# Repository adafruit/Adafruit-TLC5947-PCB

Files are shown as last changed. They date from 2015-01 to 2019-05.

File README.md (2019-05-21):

## Adafruit 24-Channel 12-bit PWM LED Driver - SPI Interface TLC5947 PCB
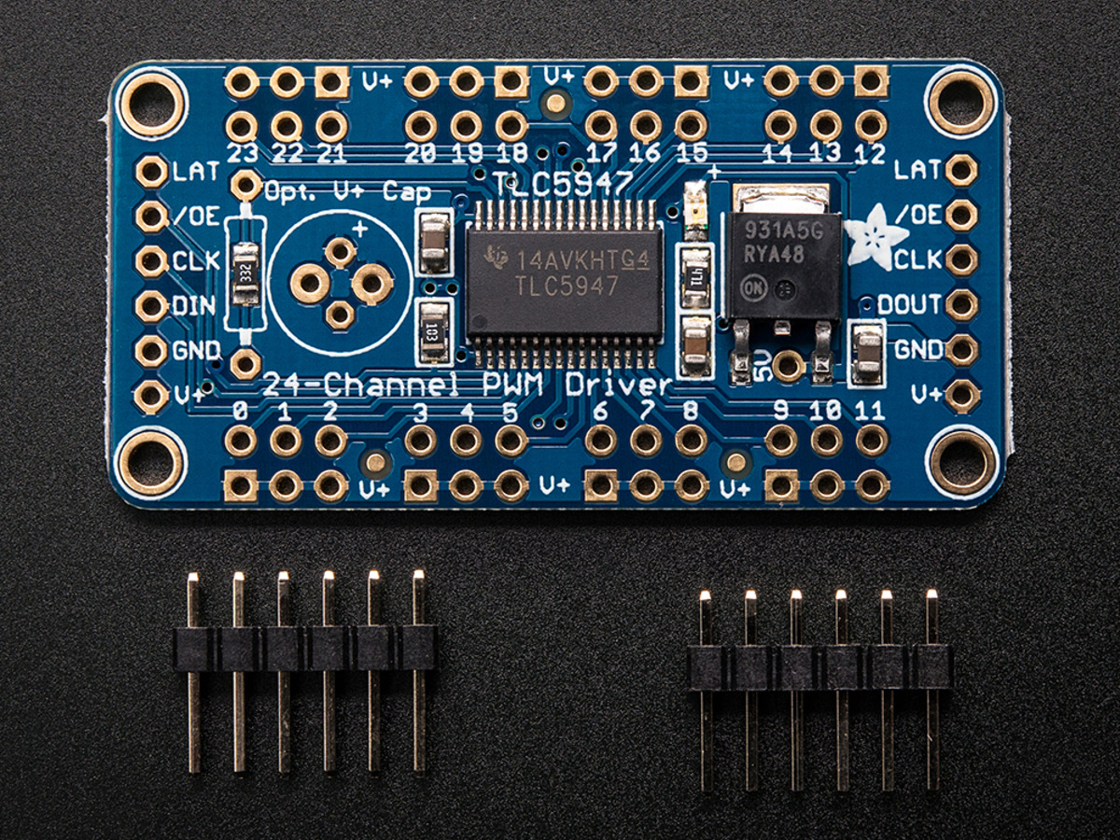
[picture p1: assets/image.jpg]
<a href="http://www.adafruit.com/products/1429"><br/>
Click here to purchase one from the Adafruit shop</a>

For all of you out there who want to control 24 channels of PWM, we salute you! We also would like you to check out this breakout board for the TLC5947 PWM driver chip. This chip can control 24 separate channels of 12-bit PWM output. Designed (and ideal) for LED control, this board is not good for driving servos. If you need to drive servos, we have a controller for that over here.

Only three "SPI" pins are required to send data (our Arduino library shows how to to use any digital microcontroller pins). Best of all, the design is completely chainable. As long as there's enough power for all the boards you can chain as many as you'd like, like a little trail of blue PCBs stretching out into the sunset. Each of the 24 output's is constant-current and open drain. You can drive multiple LEDs in series, with a V+ anode supply of up to 30V. If you want to drive something that requires a digital input, you must use a pullup resistor from the drive pin to your logic level to create the full waveform.

PCB files for Adafruit TLC5947 24-channel PWM Driver PCB. The format is EagleCAD schematic and board layout
- http://www.adafruit.com/products/1429

### License

Adafruit invests time and resources providing this open source design, please support Adafruit and open-source hardware by purchasing products from [Adafruit](https://www.adafruit.com)!

All text above must be included in any redistribution

Designed by Limor Fried/Ladyada for Adafruit Industries.
Creative Commons Attribution/Share-Alike, all text above must be included in any redistribution. 
See license.txt for additional information.

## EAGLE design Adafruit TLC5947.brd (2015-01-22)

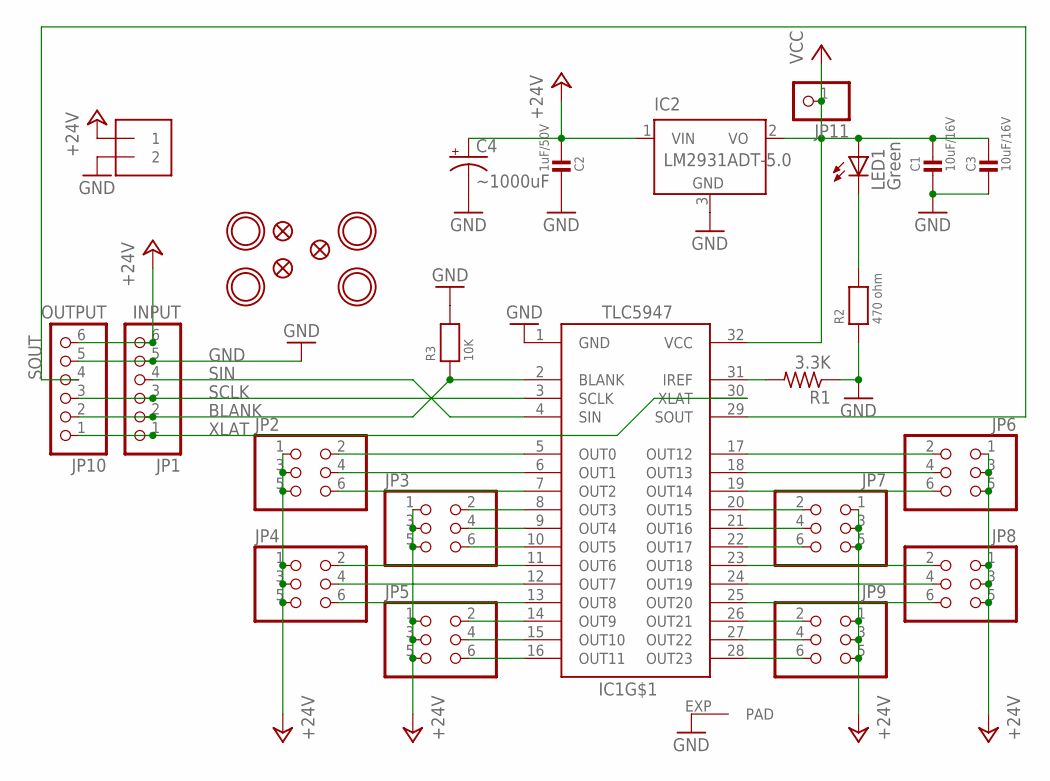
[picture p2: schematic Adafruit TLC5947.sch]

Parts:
C1, C3: 10uF/16V; 0805
C2: 1uF/50V; 0805
C4: ~1000uF; E3,5-8
FID1, FID2, FID3: FIDUCIAL""; FIDUCIAL_1MM
IC1: TLC5947-DAP; HTSSOP32DAP
IC2: LM2931ADT-5.0; TO252
J1: 1X2-3.5MM
JP1: INPUT; 1X06-CLEANBIG
JP2, JP3, JP4, JP5, JP6, JP7, JP8, JP9: HEADER-2X3; 2X03_ROUND_70MIL
JP10: OUTPUT; 1X06-CLEANBIG
JP11: PINHD-1X1CB; 1X01-CLEANBIG
LED1: Green; CHIP-LED0805
R1: 3.3K; 0805-THM
R2: 470 ohm; 0805
R3: 10K; 0805
U$1, U$2, U$3, U$4: MOUNTINGHOLE2.5; MOUNTINGHOLE_2.5_PLATED

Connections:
+24V: C2.1, C4.+, IC2.1 (VIN), J1.1, JP1.6, JP2.1, JP2.3, JP2.5, JP3.1, JP3.3, JP3.5, JP4.1, JP4.3, JP4.5, JP5.1, JP5.3, JP5.5, JP6.1, JP6.3, JP6.5, JP7.1, JP7.3, JP7.5, JP8.1, JP8.3, JP8.5, JP9.1, JP9.3, JP9.5, JP10.6
BLANK: IC1.2 (BLANK), JP1.2, JP10.2, R3.1
GND: C1.2, C2.2, C3.2, C4.-, IC1.1 (GND), IC1.EXP (PAD), IC2.3 (GND), J1.2, JP1.5, JP10.5, R1.1, R2.1, R3.2
unnamed: LED1.C, R2.2
unnamed: IC1.31 (IREF), R1.2
unnamed: IC1.5 (OUT0), JP2.2
unnamed: IC1.6 (OUT1), JP2.4
unnamed: IC1.7 (OUT2), JP2.6
unnamed: IC1.8 (OUT3), JP3.2
unnamed: IC1.9 (OUT4), JP3.4
unnamed: IC1.10 (OUT5), JP3.6
unnamed: IC1.11 (OUT6), JP4.2
unnamed: IC1.12 (OUT7), JP4.4
unnamed: IC1.13 (OUT8), JP4.6
unnamed: IC1.14 (OUT9), JP5.2
unnamed: IC1.15 (OUT10), JP5.4
unnamed: IC1.16 (OUT11), JP5.6
unnamed: IC1.26 (OUT21), JP9.2
unnamed: IC1.27 (OUT22), JP9.4
unnamed: IC1.28 (OUT23), JP9.6
unnamed: IC1.23 (OUT18), JP8.2
unnamed: IC1.24 (OUT19), JP8.4
unnamed: IC1.25 (OUT20), JP8.6
unnamed: IC1.20 (OUT15), JP7.2
unnamed: IC1.21 (OUT16), JP7.4
unnamed: IC1.22 (OUT17), JP7.6
unnamed: IC1.17 (OUT12), JP6.2
unnamed: IC1.18 (OUT13), JP6.4
unnamed: IC1.19 (OUT14), JP6.6
SCLK: IC1.3 (SCLK), JP1.3, JP10.3
SIN: IC1.4 (SIN), JP1.4
SOUT: IC1.29 (SOUT), JP10.4
VCC: C1.1, C3.1, IC1.32 (VCC), IC2.2 (VO), JP11.1, LED1.A
XLAT: IC1.30 (XLAT), JP1.1, JP10.1

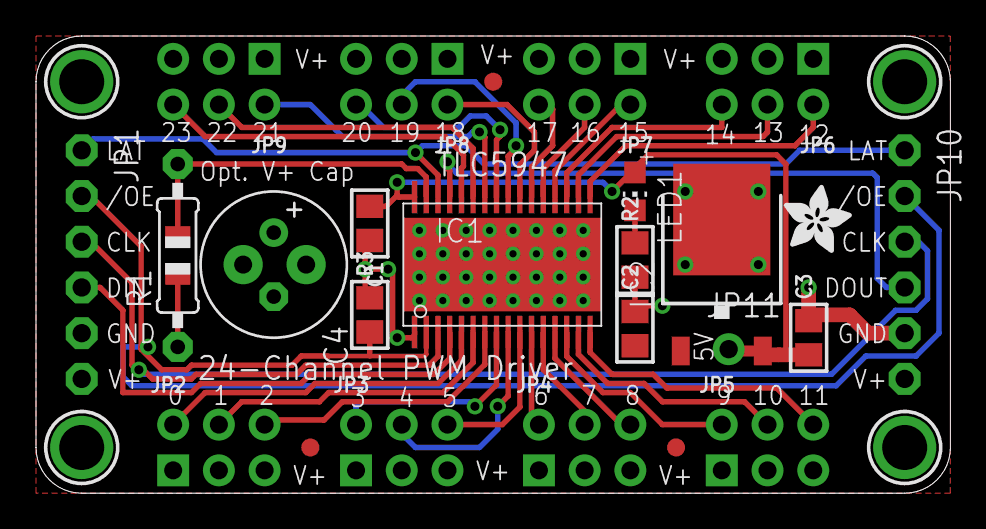
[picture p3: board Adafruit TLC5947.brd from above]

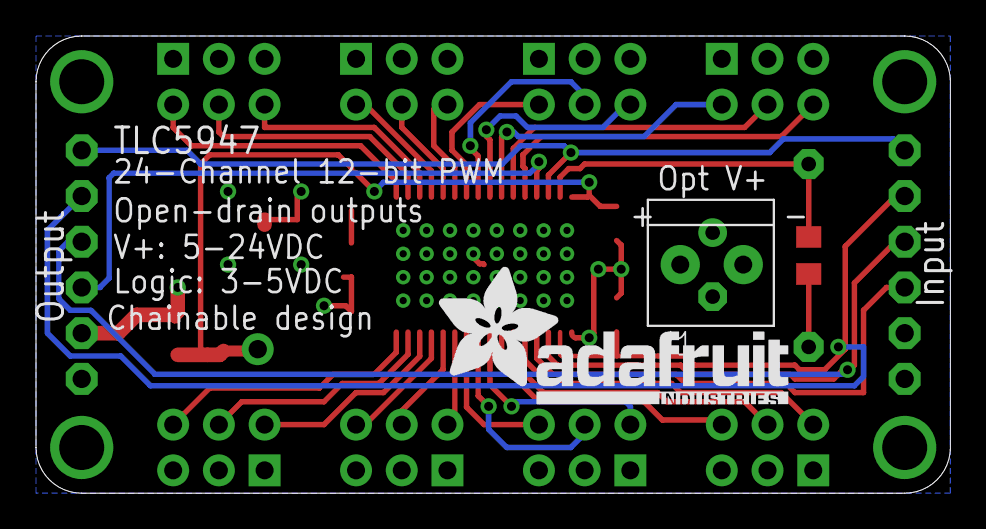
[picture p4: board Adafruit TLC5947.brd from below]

Board: 2 copper layers, 50.8 x 25.4 mm, 31 parts (2 on the bottom side), 34 nets.

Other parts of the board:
U$5: ADAFRUIT_TEXT_20MM
U$6: ADAFRUIT_3.5MM

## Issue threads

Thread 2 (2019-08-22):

Erroneous PWM

andrey-gvrd, 2019-08-22:
I'm having issues with erroneous PWM outputs. Happens only when the PWM channel is being continuously updated.

In this image the PWM value is being slowly changed, but there's a wrong value circled:
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

Even if I increase the delay between writes to 100ms (which is already too much for my use case), the problem remains.

Here's the code:
```
#include "Adafruit_TLC5947.h"

#define NUM_TLC5974 1

#define CLOCK_PIN 6
#define LATCH_PIN 8
#define DATA_PIN  9

Adafruit_TLC5947 tlc = Adafruit_TLC5947(NUM_TLC5974, CLOCK_PIN, DATA_PIN, LATCH_PIN);

void setup() {
  tlc.begin();
}

#define MIN 3000
#define MAX 4095
#define STEP 10

void loop() {
  for (int32_t i = MIN; i < MAX; i += STEP) {
    tlc.setPWM(1, i);
    tlc.write();
    delay(10);
  }
  delay(500);
  for (int32_t i = MAX; i > MIN; i -= STEP) {
    tlc.setPWM(1, i);
    tlc.write();
    delay(10);
  }
  delay(500);
}
```

ladyada, 2019-08-22:
not much you can do about it, its cause the chip is updating the PWM at the same time as outputting, and you get an overlap (rarely). its in hardware.

andrey-gvrd, 2019-08-22:
Ok, that's what I thought.

This seems like a deal-breaker for most applications where the PWM outputs are not constant -- dimming looks absolutely horrible. Am I wrong?

I'm finding some combinations of `STEP` and `delay(T)` to be particularly terrible.

STEP 100 and `delay(10)` are OK.

andrey-gvrd, 2019-08-22:
Ok, that's what I thought.

I'm kinda surprised it's implemented this way -- wouldn't it make more sense to update the PWM output at the end of the period instead of in the middle?

I'm finding some tie between STEP and `delay(T)` and the resulting flicker when dimming. Probably some kind of aliasing effect?

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

Kinda off topic, but does your PCA9685 have the same issue?

andrey-gvrd, 2019-08-22:
Also probably unrelated to this topic, but it says [here](https://learn.adafruit.com/tlc5947-tlc59711-pwm-led-driver-breakout?view=all) that "The TLC5947 has a fixed PWM frequency in the high megahertz range which is good for driving LEDs." but I'm seeing a little over a a kilohertz on the output.

ladyada, 2019-08-23:
I think PC9685 does not, or at least we've not seen it.
https://cdn-shop.adafruit.com/datasheets/tlc5947.pdf
has all info, there's up to 15mhz SPI data rate. that's not the LED itself - removed that text, the guide author was confused. the LEDs may not be that high (its actually not even specified int he datasheet!)

andrey-gvrd, 2019-08-29:
PCA9685 works perfectly.

Closed 2019-08-29.

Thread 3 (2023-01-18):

OE (Blanking) Input to the board

AlanGitMan, 2023-01-18:
The existing board has a pull-down resistor on the OE/Blanking input line.

Whether or not you define an Arduino pin to control OE (as suggested in the library code) during Arduino resets and updates the LEDs you have connected to the TLC5947 will blink and flash randomly at full brightness because the Arduino pins have all gone tri-state temporarily.  This will happen even if you do define and connect an Arduino pin to OE, because that pin will also go tri-state when no code is running.

This is not acceptable in some applications (mine is one) and I could foresee that, in some multi-board setups, it could unduly stress the power supply if multiple boards and (potentially) dozens of LEDs are connected.  All this happens because the pull-down resistor on the board is essentially defaulting the display to be enabled in the absence of any active MCU connection.

Another issue is that there is little or no documentation on the OE line function in the product support literature.

I would suggest that in any future version of this board:

1. Physical pull-up and pull-down resistors are provided for the blanking input and a 3 pin header with a user changeable link (please, not solder links!) is provided to provide the choice of making the blanking function default to ON or OFF when no code is running. With this arrangement, an Arduino pin can - as now - still be optionally used to provide software control when the code is running.

2. Some documentation is provided on the use and purposes of the OE function (I'd be happy to write something if asked) so that people can understand how to set things up as they need for their usage of the board.

Alan T

maxroseGIT, 2025-03-29:
A very reasonable request from @AlanGitMan.

Adafruit, please consider this!

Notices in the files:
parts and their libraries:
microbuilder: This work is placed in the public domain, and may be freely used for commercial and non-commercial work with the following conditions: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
